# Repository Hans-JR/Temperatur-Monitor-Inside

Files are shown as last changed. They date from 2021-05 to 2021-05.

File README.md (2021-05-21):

# Temperatur-Monitor-Inside
A Monitor to display the various temperatur sensors inside a boat

Required hardware: Arduino mini (a ATMega 168 is sufficient) , LCD Display 4 x 20 with I2C-adapter FC113, DS1820B, 12 to 5V DC-DC adapter, LDR, active beeper

The address of the DS1820B has to be identified and inserted into the code prior programming. The display can be dimmed in darkness. The threshold of the dimming can be adapted by changing the value "if(analogRead(3)>= 190) //threshold" The min brightness is defined by the value " analogWrite(LCDPin, 10); // dimmed brightness"
An alarm will be triggered, if the the temp of the "Auspuff" (exhaust) goes above the value in "float TempAlarm = 70; // hier die maximale Temperatur für "Auspuff" eingeben". In this case the value is set to 70 degrees C.

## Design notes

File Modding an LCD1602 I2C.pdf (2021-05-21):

### Modding an LCD1602 I2C/IIC Adapter Board to enable external PWM LCD backlight control

ict-bits: Modding an LCD1602 I2C/IIC Adapter Board to enable external PWM LCD backlight control

A big disadvantage of prototyping with LCD1602 character LCD displays is the amount of I/0-pins you need. Of course you can make use of the 4-bit control mode instead of the 8-bit, but you stil need at least 7 I/O-pins.

It's a better idea to use a cheap IIC/I2C adapter board. This enables you to control an LCD (including the backlight) with only 2 I/O pins (SDA & SCL).

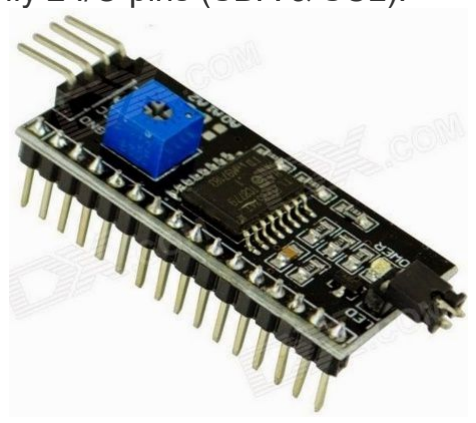
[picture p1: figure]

These adapter boards contain a transistor driver to control the LCD backlight. The transistor base is driven by an I/O-pin of the onboard PCF8574. This works great to enable or disable the backlight, but it's "on" or "off". Dimming is not possible because the PCF8574 does not support PWM output.

For prototyping purposes I decided to use an external transistor driver on my Arduino Proto Shield.
Via jumpers I can choose what I want: ON/OFF (standard setting) via I2C or Dimmable via external PWM. This is how I did it.

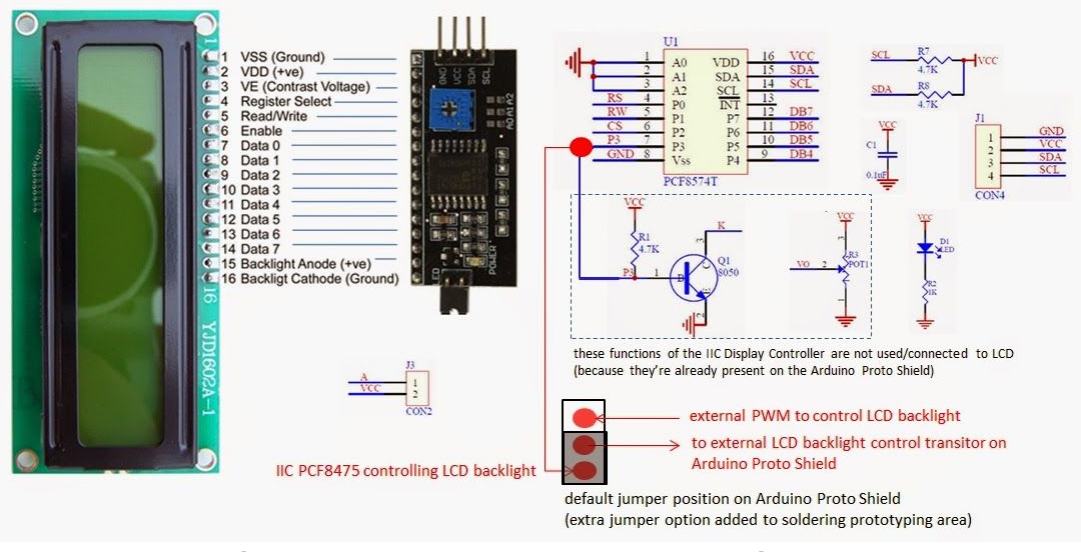
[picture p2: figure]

First I had to find out which PCF8574 pin was driving the LCD-backlight transistor. After a quick search I found out that is it pin 7.
So, to bring that signal out to my Arduino Proto Shield, I had to solder an extra wire to the PFC8574.

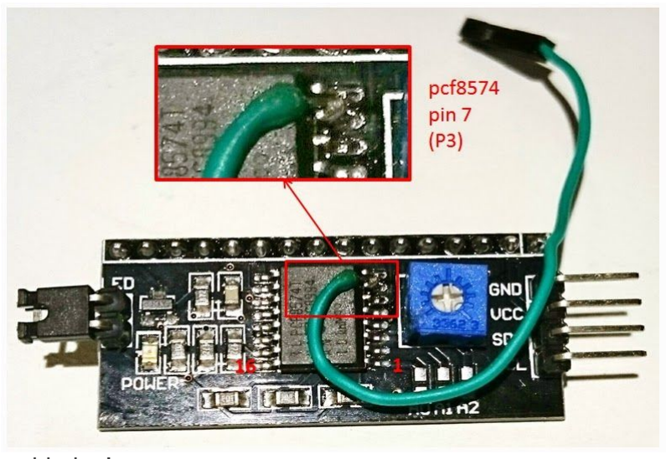
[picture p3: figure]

That's it! Happy soldering!

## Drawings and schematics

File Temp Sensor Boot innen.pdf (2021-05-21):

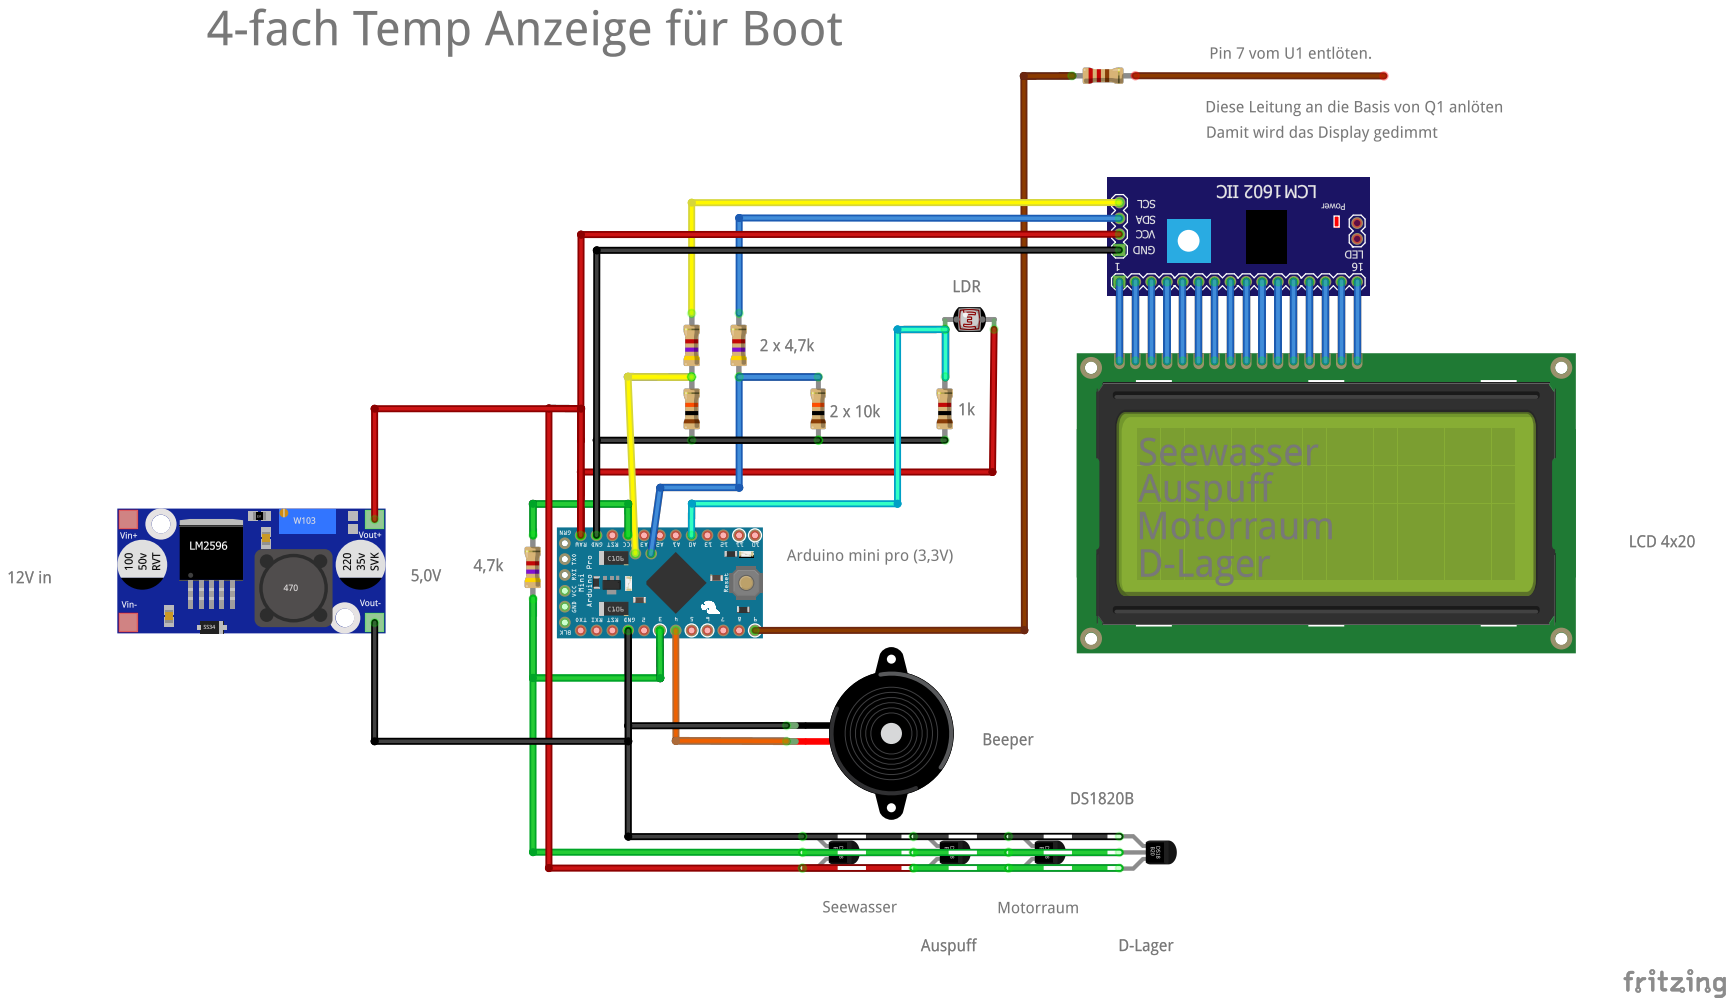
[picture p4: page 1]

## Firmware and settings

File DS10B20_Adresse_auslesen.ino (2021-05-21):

// mit diesem Programm werden die Adressen der DS18B20 Sensoren 
// im seriellen Monitor auf dem PC ausgegeben
// Der Sensor wird an Pin 3 angeschlossen

#include <OneWire.h>

OneWire  ds(3);  // Anschluss an PIN 3

void setup(void) {
  Serial.begin(9600);
  discoverOneWireDevices();
}

void discoverOneWireDevices(void) {
  byte i;
  byte present = 0;
  byte data[12];
  byte addr[8];
  
  Serial.print("Nach 1 Leitung Sensor suchen\n\r");
  while(ds.search(addr)) {
    Serial.print("\n\rGefunden \'1-Wire\' fuehler mit der Adresse:\n\r");
    for( i = 0; i < 8; i++) {
      Serial.print("0x");
      if (addr[i] < 16) {
        Serial.print('0');
      }
      Serial.print(addr[i], HEX);
      if (i < 7) {
        Serial.print(", ");
      }
    }
    if ( OneWire::crc8( addr, 7) != addr[7]) {
        Serial.print("CRC is not valid!\n");
        return;
    }
  }
  Serial.print("\n\r\n\rDas war es... mehr kommmt nicht:)\r\n");
  ds.reset_search();
  return;
}

void loop(void) {
  // nothing to see here
}
  

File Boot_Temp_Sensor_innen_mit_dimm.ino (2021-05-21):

#include <OneWire.h>
#include <DallasTemperature.h>
#include <LiquidCrystal_I2C.h>

// set the I2C address to 0x3f
// for 4 line display with 20 char per line
// connect I2C Adapter as follows: A4 - SDA, A5 - SCL
// connect DS18B20 to pin D3
// connect Buzzer to pin D4
// Pin 7 von U1 auf dem I2C-Board entlöten
// den Basisanschluss von Q1 über einen 220Ohm Widerstand mit Pin D9 (int LCDPin = 9;) verbinden
// Der Widerstand für den Helligkeitssensor beträgt 1kOhm
// Der Eingangspin für den Helligkeitssensor ist A0: "(analogRead(0)"
// Die Programme werden mit dem USBasp Programmer geladen
// Die Einstellungen für das Board: ATMega 168, Internal, 8Mhz, ohne Bootloader, Variant 168PA

LiquidCrystal_I2C lcd(0x3f, 2, 1, 0, 4, 5, 6, 7, 3, POSITIVE);
constexpr uint8_t BuzzerPin = 4;
int LCDPin = 9; // PWM-Ausgangs-Pin für das Display

#define ONE_WIRE_BUS 3
OneWire oneWire(ONE_WIRE_BUS);
DallasTemperature sensors(&oneWire);

// aktuelle Adressen der Sensoren
// Seewasser: 28FF88056E1801A9
// Auspuff:   28FFE6196E180130
// Motorraum: 28FF516B6D180165
// Drucklager:28FF0BF6681803B8

float Temperatur[4];
float TempAlarm = 70; // hier die maximale Temperatur für "Auspuff" eingeben

// Sensoren 0-3 feste Vorgabe der Adressen der Temperatursensoren
DeviceAddress Sensor0 = {0x28, 0xFF, 0x88, 0x05, 0x6E, 0x18, 0x01, 0xA9}; // Seewasser
DeviceAddress Sensor1 = {0x28, 0xFF, 0xE6, 0x19, 0x6E, 0x18, 0x01, 0x30}; // Auspuff
DeviceAddress Sensor2 = {0x28, 0xFF, 0x51, 0x6B, 0x6D, 0x18, 0x01, 0x65}; // Motorraum
DeviceAddress Sensor3 = {0x28, 0xFF, 0x0B, 0xF6, 0x68, 0x18, 0x03, 0xB8}; // Drucklager

void setup() {
  lcd.begin(20, 4);
  lcd.clear();
  lcd.backlight();
  sensors.begin();
  pinMode(BuzzerPin, OUTPUT);
}

void loop() {
  sensors.requestTemperatures();
  Temperatur[0] = sensors.getTempC(Sensor0);
  Temperatur[1] = sensors.getTempC(Sensor1);
  Temperatur[2] = sensors.getTempC(Sensor2);
  Temperatur[3] = sensors.getTempC(Sensor3);

  lcd.setCursor(1, 0);
  lcd.print("Seewasser: ");
  lcd.print(Temperatur[0]);
  lcd.setCursor(17, 0);
  lcd.write(223);             // ergibt das "Grad" Zeichen
  lcd.print("C  ");

  lcd.setCursor(1, 1);
  lcd.print("Auspuff  : ");
  lcd.print(Temperatur[1]);
  lcd.setCursor(17, 1);
  lcd.write(223);
  lcd.print("C  ");

  lcd.setCursor(1, 2);
  lcd.print("Motorraum: ");
  lcd.print(Temperatur[2]);
  lcd.setCursor(17, 2);
  lcd.write(223);
  lcd.print("C  ");

  lcd.setCursor(1, 3);
  lcd.print("Dr-Lager : ");  
  lcd.print(Temperatur[3]);
  lcd.setCursor(17, 3);
  lcd.write(223);
  lcd.print("C  ");

  if (Temperatur[1] > TempAlarm) {            // Temp Wert "Auspuff" mit "TempAlarm" vergleichen
    digitalWrite(BuzzerPin, HIGH);
    delay(1000);
    digitalWrite(BuzzerPin, LOW);
  }
  delay(5000);
  
if(analogRead(0)>= 190)
  analogWrite(LCDPin, 255);
else
  analogWrite(LCDPin, 10);  
}
